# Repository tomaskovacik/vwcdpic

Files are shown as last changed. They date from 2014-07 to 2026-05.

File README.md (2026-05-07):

You can buy boards or finished emu at my store at tindie:



Full backup/mirror of original vwcdpic site is on <a href="https://web.archive.org/web/20110817024153/http://www.k9spud.com/vwcdpic/">archive.org</a>

<a href="https://github.com/tomaskovacik/vwcdpic/blob/master/vwcdpic-2.8pre3.asm">vwcdpic-2.8pre3.asm</a> - latest sourcecode on internet, with my <a href="https://github.com/tomaskovacik/vwcdpic/commits/master/vwcdpic-2.8pre3.asm">fixies</a>
	
<a href="https://raw.githubusercontent.com/tomaskovacik/vwcdpic/master/vwcdpic-3.x-2.7d-RCD300-1-pic12f629.hex">vwcdpic-3.x-2.7d-RCD300-1-pic12f629.hex</a> is only version works with RCD300 head unit(black one, no silver), if it works with other, for which 2.8 didn't, let me know please.

for ipod support look <a href="https://web.archive.org/web/20090427105500/http://www.k9spud.com/vwcdpic/devel/vwcdpic3/flash/">here</a>

<a href="https://web.archive.org/web/20090427105500/http://www.k9spud.com/vwcdpic/devel/vwcdpic-2.7d/ipod-vw-2.1.asm">iPod-VW Firmware v2.1 Source Code</a> - Use this for iPod 3G+ remote control support on most head units

<a href="https://web.archive.org/web/20090427105500/http://www.k9spud.com/vwcdpic/devel/vwcdpic3/flash/ipod-vw-2.2/ipod-vw-2.2.ConcertII_G5-3.x.asm">iPod-VW Firmware v2.2-Concert II Source Code</a> - Use this for iPod 4G/5G remote control support on Audi Concert II head units 

assemble plan for SMD version generated using <a href="https://github.com/openscopeproject/InteractiveHtmlBom">InteractiveHtmlBom</a> is <a href="https://tomaskovacik.github.io/vwcdpic/hw/bom/ibom.html">here</a>

assemble plan for THT version generated using <a href="https://github.com/openscopeproject/InteractiveHtmlBom">InteractiveHtmlBom</a> is <a href="https://tomaskovacik.github.io/vwcdpic/hw/bom_THT/ibom.html">here</a>

notes:
-------
2.8pre3
- better works with audi concert1/chorus1 head unit made by blaupunkt (previous,next CD works)
- switching from CDC to radio back to CDC works on concert1/chorus1
- tested with:
	- audi concert 1(blaupunkt)
	- audi concert 1(philips)
	- audi concert 2
	- chorus1(blaupunkt)
	- Symphony I
	- vw blaupunkt RadioNavigationSystem MCD
	- VW Passat Blaupunkt Gamma (similar to Gamma V)
	- Audi Symphony II BOSE
	- original project <a href="https://web.archive.org/web/20110811154456/http://www.k9spud.com/wiki/VWCDPIC:Compatible_Head_Units">list</a>
	
		- <a href="https://web.archive.org/web/20110811154456/http://www.k9spud.com/wiki/VWCDPIC:Compatible_Head_Units#Volkswagen">Volkswagen</a>
		
			- <a href="https://web.archive.org/web/20110811154456/http://www.k9spud.com/wiki/VWCDPIC:Compatible_Head_Units#New_Beetle">New Beetle</a>
			
			- <a href="https://web.archive.org/web/20110811154456/http://www.k9spud.com/wiki/VWCDPIC:Compatible_Head_Units#Touareg">Touareg</a>
			
			- <a href="https://web.archive.org/web/20110811154456/http://www.k9spud.com/wiki/VWCDPIC:Compatible_Head_Units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">Passat B3/B4 (1993+)</a>
			
			- <a href="https://web.archive.org/web/20110811154456/http://www.k9spud.com/wiki/VWCDPIC:Compatible_Head_Units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">EOS 3.2 (2008)</a>
			
			- <a href="https://web.archive.org/web/20110811154456/http://www.k9spud.com/wiki/VWCDPIC:Compatible_Head_Units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">Single DIN Monsoon</a>
			
			- <a href="https://web.archive.org/web/20110811154456/http://www.k9spud.com/wiki/VWCDPIC:Compatible_Head_Units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">Single DIN Monsoon with In-Dash CD Player</a>
			
			- <a href="https://web.archive.org/web/20110811154456/http://www.k9spud.com/wiki/VWCDPIC:Compatible_Head_Units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">Double DIN Monsoon</a>
			
			- <a href="https://web.archive.org/web/20110811154456/http://www.k9spud.com/wiki/VWCDPIC:Compatible_Head_Units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">Multi-Function Display (MFD)</a>
			
			- <a href="https://web.archive.org/web/20110811154456/http://www.k9spud.com/wiki/VWCDPIC:Compatible_Head_Units#Gamma_IV">Gamma IV</a>
			
			- <a href="https://web.archive.org/web/20110811154456/http://www.k9spud.com/wiki/VWCDPIC:Compatible_Head_Units#Gamma_V">Gamma V</a>
			
			- <a href="https://web.archive.org/web/20110811154456/http://www.k9spud.com/wiki/VWCDPIC:Compatible_Head_Units#RCD300">RCD300</a>
			
			- <a href="https://web.archive.org/web/20110811154456/http://www.k9spud.com/wiki/VWCDPIC:Compatible_Head_Units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">Blaupunkt R100</a>
			
			- <a href="https://web.archive.org/web/20110811154456/http://www.k9spud.com/wiki/VWCDPIC:Compatible_Head_Units#RNS300">RNS300</a>
			
			- <a href="https://web.archive.org/web/20110811154456/http://www.k9spud.com/wiki/VWCDPIC:Compatible_Head_Units#RN_S2_DVD">RN S2 DVD</a>

		- <a href="https://web.archive.org/web/20110811154456/http://www.k9spud.com/wiki/VWCDPIC:Compatible_Head_Units#Seat">Seat</a>
		
			- <a href="https://web.archive.org/web/20110811154456/http://www.k9spud.com/wiki/VWCDPIC:Compatible_Head_Units#Leon">Leon</a>
			
			- <a href="https://web.archive.org/web/20110811154456/http://www.k9spud.com/wiki/VWCDPIC:Compatible_Head_Units#Ibiza">Ibiza</a>

		- <a href="https://web.archive.org/web/20110811154456/http://www.k9spud.com/wiki/VWCDPIC:Compatible_Head_Units#Skoda">Skoda</a>
		
			- <a href="https://web.archive.org/web/20110811154456/http://www.k9spud.com/wiki/VWCDPIC:Compatible_Head_Units#Symphony">Symphony</a>

		- <a href="https://web.archive.org/web/20110811154456/http://www.k9spud.com/wiki/VWCDPIC:Compatible_Head_Units#Audi">Audi</a>
		
			- <a href="https://web.archive.org/web/20110811154456/http://www.k9spud.com/wiki/VWCDPIC:Compatible_Head_Units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">Audi Chorus II</a>

pinout:
--------------------
| signal | PIC pin  |
|---|---|
| +5v | 1 |
| GND | 8 |
| CLK: | 7 |
| DataIn: | 6 |
| DataOut: | 5 |
| serial 9600:  | 2 |

compile:
---------

http://www.micahcarrick.com/pic-programming-linux.html

for i in `ls *.asm|cut -d\. -f2`;do gpasm vwcdpic-2.$i.asm;done

about connectivity to music players
---------------------------------------------

all what is mentioned in archive on <a href="https://web.archive.org/web/20110817024153/http://www.k9spud.com/vwcdpic/">archive.org</a> should works.

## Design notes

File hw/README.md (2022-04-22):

HW part of vwcdpic project

- made in kicad http://kicad.org
- smd version
- tht version for home manufacture
- for better audio input level, build preamplifier: https://github.com/tomaskovacik/hw/tree/master/kicad/audio_preamplifier



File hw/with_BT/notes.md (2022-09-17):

1) - TEST OK
connect 12V to 12Vin
connect 12V to CDC_ENA_12V 
 check if 12V is present (switch Q2,Q1 works)

2)
connect jumper JP4

3) connect JP2 (R28, C34,C35 must be populated)

check if 3V6 is 3.6V, if not set using R19, R13)

program pic
connect to radio
check 3V6 voltage ripple while CDC is operational (??? or we can ignore this and listen to BT audio quality)

solder BT module, check if it connects, if so program it (disable STONES, set name etc...)

solder R4 -> enable communication PIC->BT

check audio ripple and mic bias (2V) whily BT in call

check overall audio quality

if noise from CDC is pressent, try JP1 or JP3

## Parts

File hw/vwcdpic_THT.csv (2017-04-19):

Id | Designator | Package | Quantity | Designation | Supplier and ref
1 | RADIO1 | Pin_Header_Straight_1x05 | 1 | CONN_01X05
2 | ICSP_UART1 | Pin_Header_Straight_1x04 | 1 | CONN_01X04
3 | C3,C2 | C_Rect_L7_W2.5_P5 | 2 | 100n
4 | U2 | TO92-STABIL | 1 | LM78L05ACZ
5 | U1 | DIP-8__300_ELL | 1 | PIC12F629
6 | R7,R6,R5 | Resistor_Horizontal_RM10mm | 3 | 3k3
7 | C1 | C_Radial_D5_L11_P2.5 | 1 | 1uF/6.3V
8 | R1 | Resistor_Horizontal_RM10mm | 1 | 10k

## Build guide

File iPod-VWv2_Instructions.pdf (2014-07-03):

iPod-VW Instructions

Connect the iPod to the control module and make sure the iPod is off before the head unit is turned on. Turning on the head unit should turn the iPod on. The iPod will turn on and off with the head unit as long as it is connected. If the iPod does not play within 2 seconds, pressing the “Scan” button (Play/Pause) one or more times should make the iPod play. The iPod may also be operated manually.

- Standard iPod functions

Play/Pause: “Scan” button
Previous Track: “Tune <”
Next Track: “Tune >”

There may be slight differences from radio to radio. Try all of the different buttons to discover which functions occur with each.

- Advanced iPod functions (aka “Mode 4”)

Advanced remote mode is best used when the iPod is placed in an inaccessible location, such as in the trunk or in the glove compartment. This mode most closely simulates an actual CD changer. Press the “Mix” button to place the iPod into advanced remote mode. While in this mode, all of the standard iPod functions still work. The display will now read “OK to Disconnect” and show a check mark. The iPod buttons are not usable in this mode. To return to normal mode, turn the iPod off with the head unit, then disconnect the remote connector. If the iPod will not return to normal mode, hold the “Menu” and center button down together until the iPod restarts.

The following functions are available in advanced mode:

Enter Shuffle Play Mode: “Mix”
(The iPod will pause after this command. Press “Scan” to resume play.)
Exit Shuffle Play Mode: “Tune <”
(The iPod will begin playing the track that is sequentially prior to the track you were playing.) Go to Main Playlist: “CD1”
Go to 1st Playlist: “CD2”
Go to 2nd Playlist: “CD3”
Go to 3rd Playlist: “CD4”
Go to 4th Playlist: “CD5”
Go to 5th Playlist: “CD6”
- PLAYLIST MANAGEMENT

The playlists are numbered in alphabetical order, starting with numbers. If you name your playlists “1”, “2”, “3”, “4”, and “5”, they are almost certain to be the first 5 playlists. Since iTunes displays the playlists in alphabetical order, the first 5 playlists shown under your iPod will be the 5 to play using the “CD2” – “CD6” buttons.

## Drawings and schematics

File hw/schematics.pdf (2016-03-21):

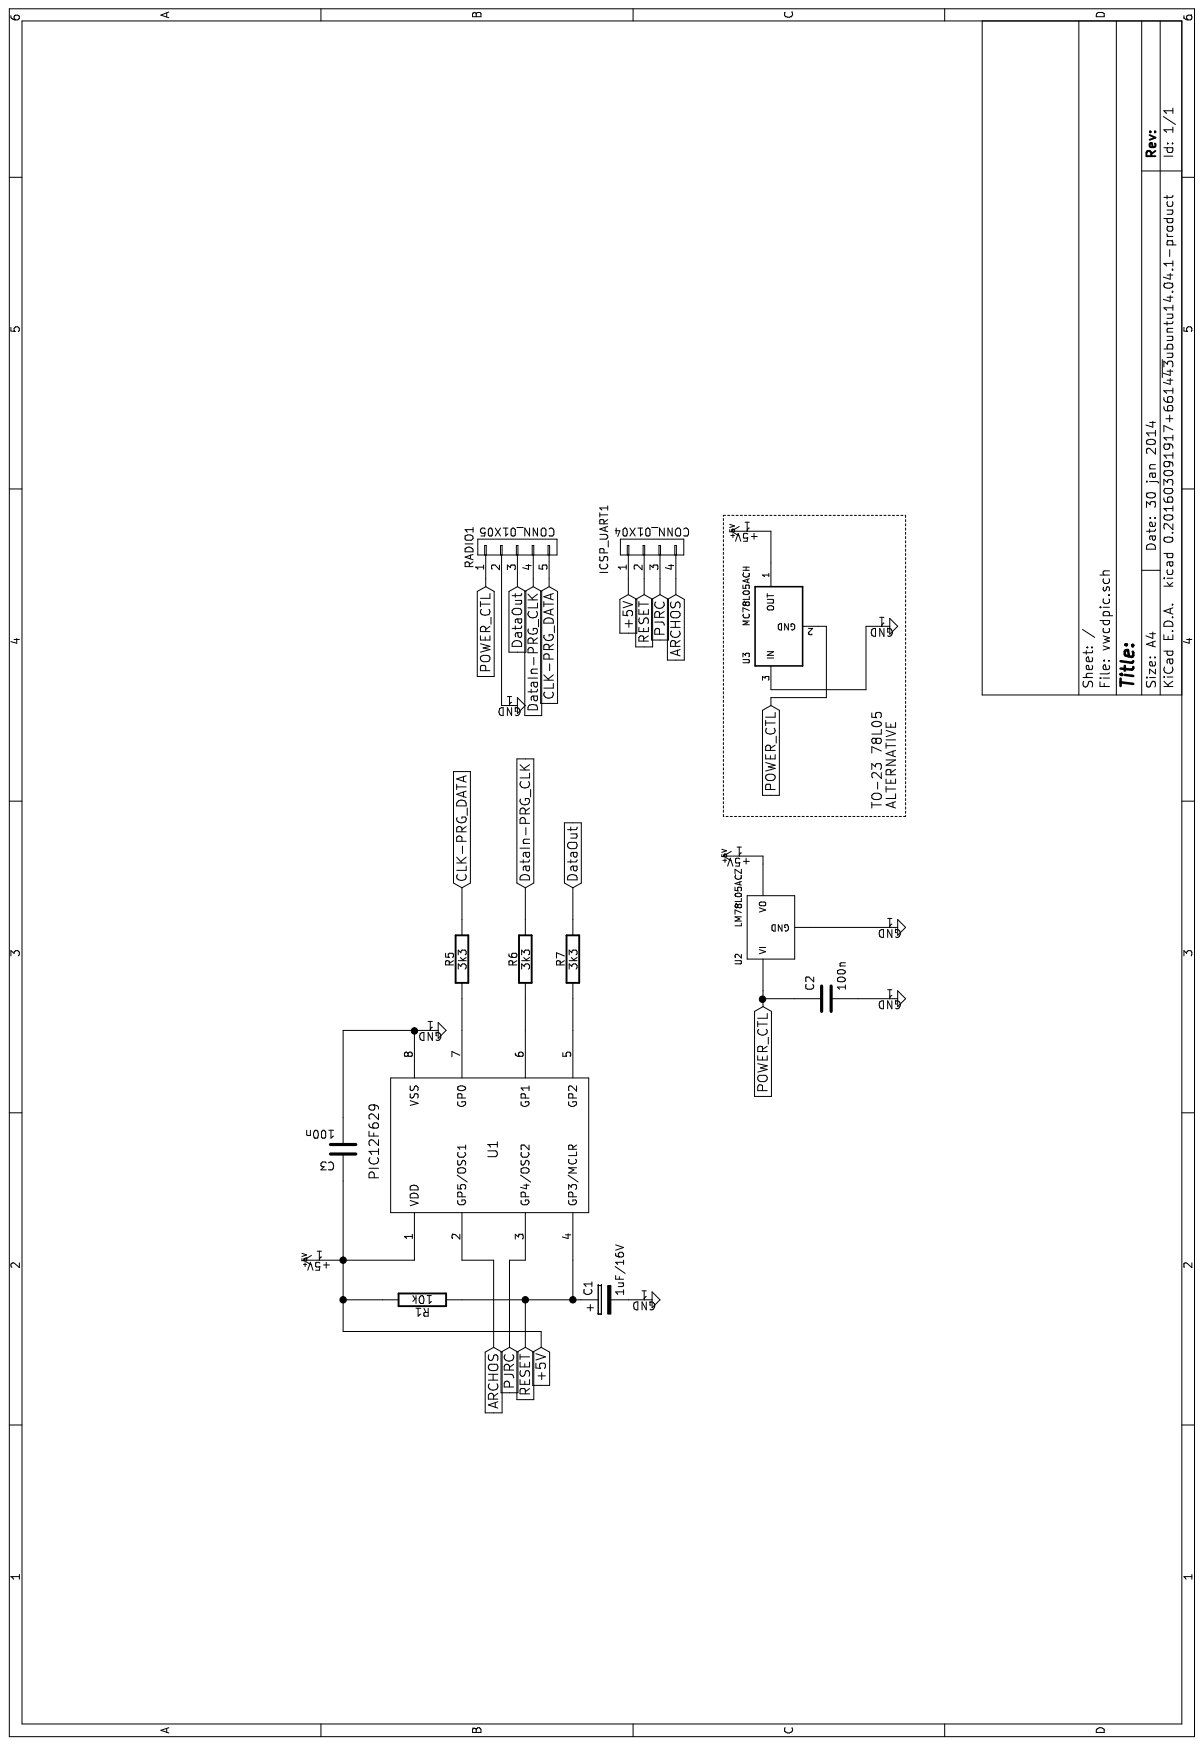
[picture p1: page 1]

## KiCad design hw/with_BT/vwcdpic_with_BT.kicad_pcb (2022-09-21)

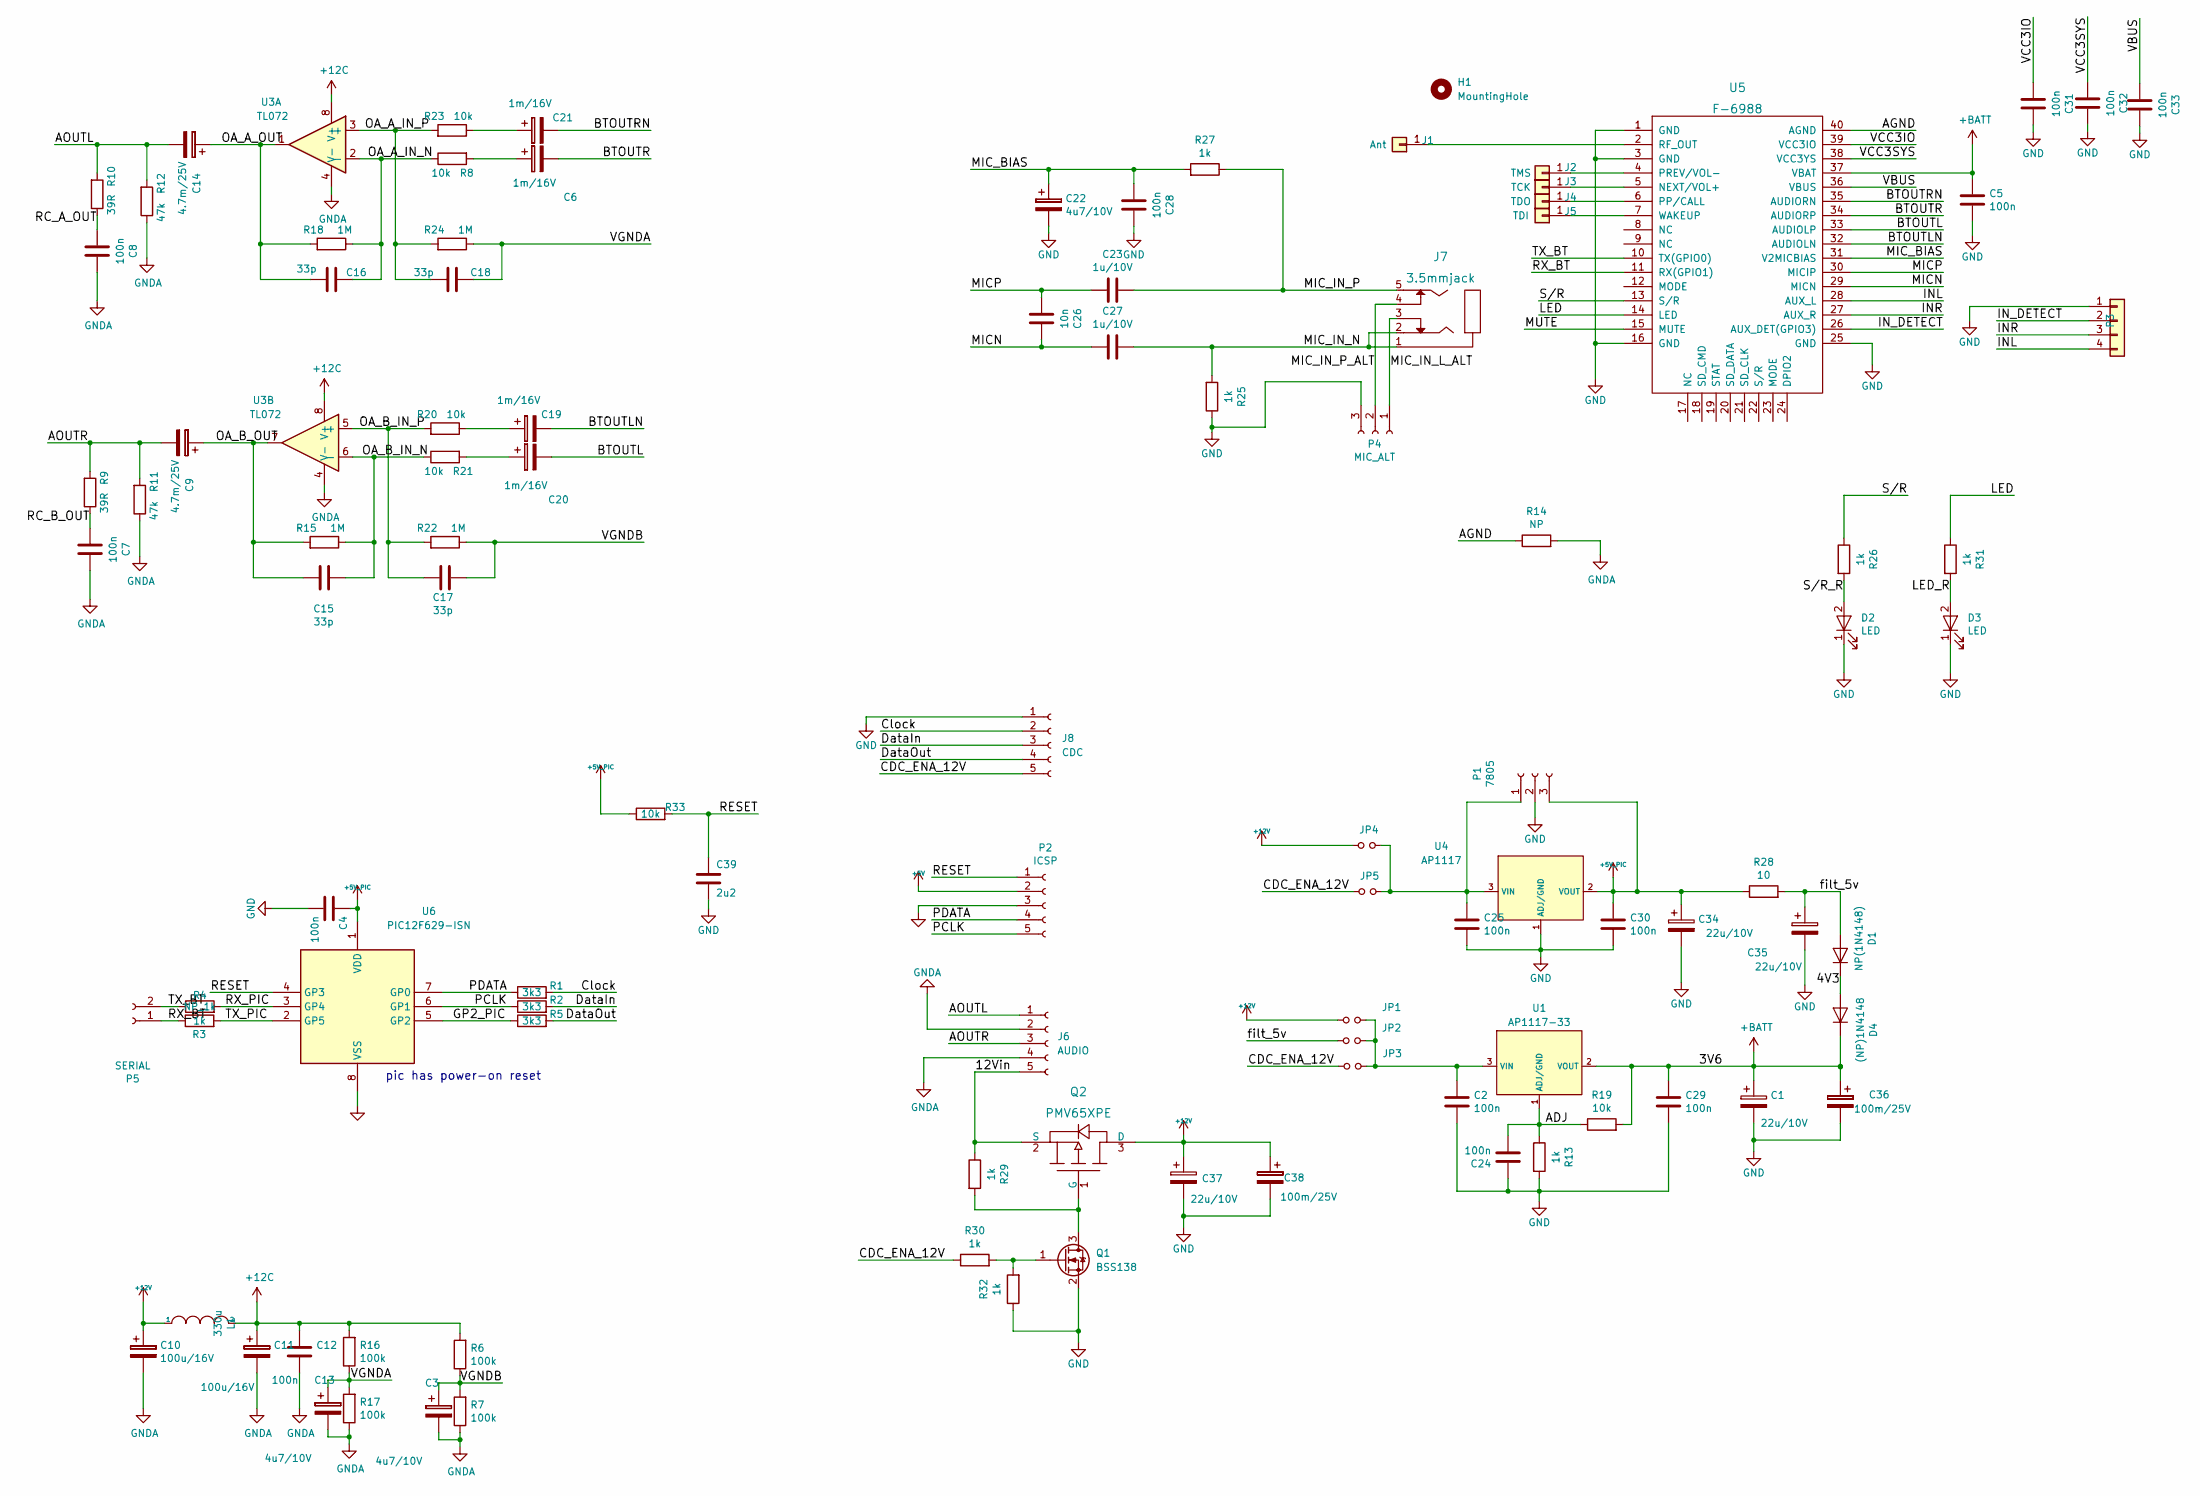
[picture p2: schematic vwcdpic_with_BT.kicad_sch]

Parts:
C1, C34, C35, C37: 22u/10V; TantalC_SizeB_EIA-3528_HandSoldering
C2, C4, C5, C7, C8, C12, C24, C25, C28, C29, C30, C31, C32, C33: 100n; C_0805_HandSoldering
C3, C13, C22: 4u7/10V; TantalC_SizeA_EIA-3216_Wave
C6, C19, C20, C21: 1m/16V; c_elec_5x5.8
C9, C14: 4.7m/25V; c_elec_5x5.8
C10, C11: 100u/16V; TantalC_SizeD_EIA-7343_HandSoldering
C15, C16, C17, C18: 33p; C_0805_HandSoldering
C23, C27: 1u/10V; C_1206_HandSoldering
C26: 10n; C_0805_HandSoldering
C36, C38: 100m/25V; c_elec_5x5.8
C39: 2u2; C_1206_HandSoldering
D1: NP(1N4148); MiniMELF_Handsoldering
D2, D3: LED; LED_0805_HandSoldering
D4: (NP)1N4148; MiniMELF_Handsoldering
H1: MountingHole; KM21
J1: Ant; 1pin_smd
J2: TMS; 1pin_smd
J3: TCK; 1pin_smd
J4: TDO; 1pin_smd
J5: TDI; 1pin_smd
J6: AUDIO; Pin_Header_Straight_1x05
J7: 3.5mmjack; 3.5mm_stereo_jack_PJ306M
J8: CDC; Pin_Header_Straight_1x05
JP1, JP2, JP3, JP4, JP5: Jumper_NO_Small; SolderJumper-2_P1.3mm_Open_TrianglePad1.0x1.5mm
L1: 330u; SMD-1210_Pol
P1: 7805; Pin_Header_Straight_1x03
P2: ICSP; Pin_Header_Straight_1x05
P3: AUX; Pin_Header_Straight_1x04
P4: MIC_ALT; Pin_Header_Straight_1x03
P5: SERIAL; Pin_Header_Straight_1x02
Q1: BSS138; SOT-23
Q2: PMV65XPE; SOT-23
R1, R2, R5: 3k3; R_0805_HandSoldering
R3, R13, R25, R26, R27, R29, R30, R31, R32: 1k; R_0805_HandSoldering
R4: NP_1k; R_0805_HandSoldering
R6, R7, R16, R17: 100k; R_0805_HandSoldering
R8, R19, R20, R21, R23, R33: 10k; R_0805_HandSoldering
R9, R10: 39R; R_0805_HandSoldering
R11, R12: 47k; R_0805_HandSoldering
R14: NP; R_0805_HandSoldering
R15, R18, R22, R24: 1M; R_0805_HandSoldering
R28: 10; R_0805_HandSoldering
U1: AP1117-33; AB2_SOT223
U3: TL072; SOIC-8-N
U4: AP1117; AB2_SOT223
U5: F-6988
U6: PIC12F629-ISN; SOIC-8-W_long_pads

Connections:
+12C: C11.1, C12.1, L1.2, R6.2, R16.2, U3.8 (V+)
+12V: C10.1, C37.1, C38.1, JP1.1, JP4.1, L1.1, Q2.3 (D)
+BATT: C1.1, C5.1, C29.1, C36.1, D4.1 (K), R19.2, U1.2 (VOUT), U5.37 (VBAT)
/4V3: D1.1 (K), D4.2 (A)
/12Vin: J6.5, Q2.2 (S), R29.1
/ADJ: C24.2, R13.1, R19.1, U1.1 (ADJ/GND)
/AGND: R14.1, U5.40 (AGND)
/AOUTL: C14.2, J6.1, R10.2, R12.2
/AOUTR: C9.2, J6.3, R9.2, R11.2
/BTOUTL: C20.2, U5.33 (AUDIOLP)
/BTOUTLN: C19.2, U5.32 (AUDIOLN)
/BTOUTR: C6.2, U5.34 (AUDIORP)
/BTOUTRN: C21.2, U5.35 (AUDIORN)
/CDC_ENA_12V: J8.5, JP3.1, JP5.1, R30.1
/Clock: J8.2, R1.2
/DataIn: J8.3, R2.2
/DataOut: J8.4, R5.2
/GP2_PIC: R5.1, U6.5 (GP2)
/INL: P3.4, U5.28 (AUX_L)
/INR: P3.3, U5.27 (AUX_R)
/IN_DETECT: P3.2, U5.26 (AUX_DET(GPIO3))
/LED: R31.1, U5.14 (LED)
/LED_R: D3.2 (A), R31.2
/MICN: C26.2, C27.1, U5.29 (MICN)
/MICP: C23.1, C26.1, U5.30 (MICIP)
/MIC_BIAS: C22.1, C28.1, R27.2, U5.31 (V2MICBIAS)
/MIC_IN_L_ALT: J7.3, P4.1
/MIC_IN_N: C27.2, J7.1, J7.2, R25.2
/MIC_IN_P: C23.2, J7.5, R27.1
/MIC_IN_P_ALT: J7.4, P4.2
/MUTE: U5.15 (MUTE)
/OA_A_IN_N: C16.2, R8.1, R18.1, U3.2 (-)
/OA_A_IN_P: C18.1, R23.2, R24.2, U3.3 (+)
/OA_A_OUT: C14.1, C16.1, R18.2, U3.1
/OA_B_IN_N: C15.2, R15.1, R21.1, U3.6 (-)
/OA_B_IN_P: C17.1, R20.2, R22.2, U3.5 (+)
/OA_B_OUT: C9.1, C15.1, R15.2, U3.7
/PCLK: P2.5, R2.1, U6.6 (GP1)
/PDATA: P2.4, R1.1, U6.7 (GP0)
/RC_A_OUT: C8.1, R10.1
/RC_B_OUT: C7.1, R9.1
/RESET: C39.1, P2.1, R33.2, U6.4 (GP3)
/RX_BT: P5.1, R3.1, U5.11 (RX(GPIO1))
/RX_PIC: R4.2, U6.3 (GP4)
/S/R: R26.1, U5.13 (S/R)
/S/R_R: D2.2 (A), R26.2
/TX_BT: P5.2, R4.1, U5.10 (TX(GPIO0))
/TX_PIC: R3.2, U6.2 (GP5)
/VBUS: C33.1, U5.36 (VBUS)
/VCC3IO: C31.1, U5.39 (VCC3IO)
/VCC3SYS: C32.1, U5.38 (VCC3YS)
/VGNDA: C13.1, C18.2, R16.1, R17.2, R24.1
/VGNDB: C3.1, C17.2, R6.1, R7.2, R22.1
/filt_5v: C35.1, D1.2 (A), JP2.1, R28.2
GND: C1.2, C2.2, C4.2, C5.2, C22.2, C24.1, C25.2, C28.2, C29.2, C30.2, C31.2, C32.2, C33.2, C34.2, C35.2, C36.2, C37.2, C38.2, C39.2, D2.1 (K), D3.1 (K), J8.1, P1.2, P2.3, P3.1, P4.3, Q1.2 (S), R13.2, R25.1, R32.1, U4.1 (ADJ/GND), U5.1 (GND), U5.3 (GND), U5.16 (GND), U5.25 (GND), U6.8 (VSS)
GNDA: C3.2, C7.2, C8.2, C10.2, C11.2, C12.2, C13.2, J6.2, J6.4, R7.1, R11.1, R12.1, R14.2, R17.1, U3.4 (V-)
unnamed: C2.1, JP1.2, JP2.2, JP3.2, U1.3 (VIN)
unnamed: C6.1, R8.2
unnamed: C19.1, R20.1
unnamed: C20.1, R21.2
unnamed: C21.1, R23.1
unnamed: C25.1, JP4.2, JP5.2, P1.1, U4.3 (VIN)
unnamed: J1.1, U5.2 (RF_OUT)
unnamed: J2.1, U5.4 (PREV/VOL-)
unnamed: J3.1, U5.5 (NEXT/VOL+)
unnamed: J4.1, U5.6 (PP/CALL)
unnamed: J5.1, U5.7 (WAKEUP)
unnamed: Q1.1 (G), R30.2, R32.2
unnamed: Q1.3 (D), Q2.1 (G), R29.2

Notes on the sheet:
pic has power-on reset

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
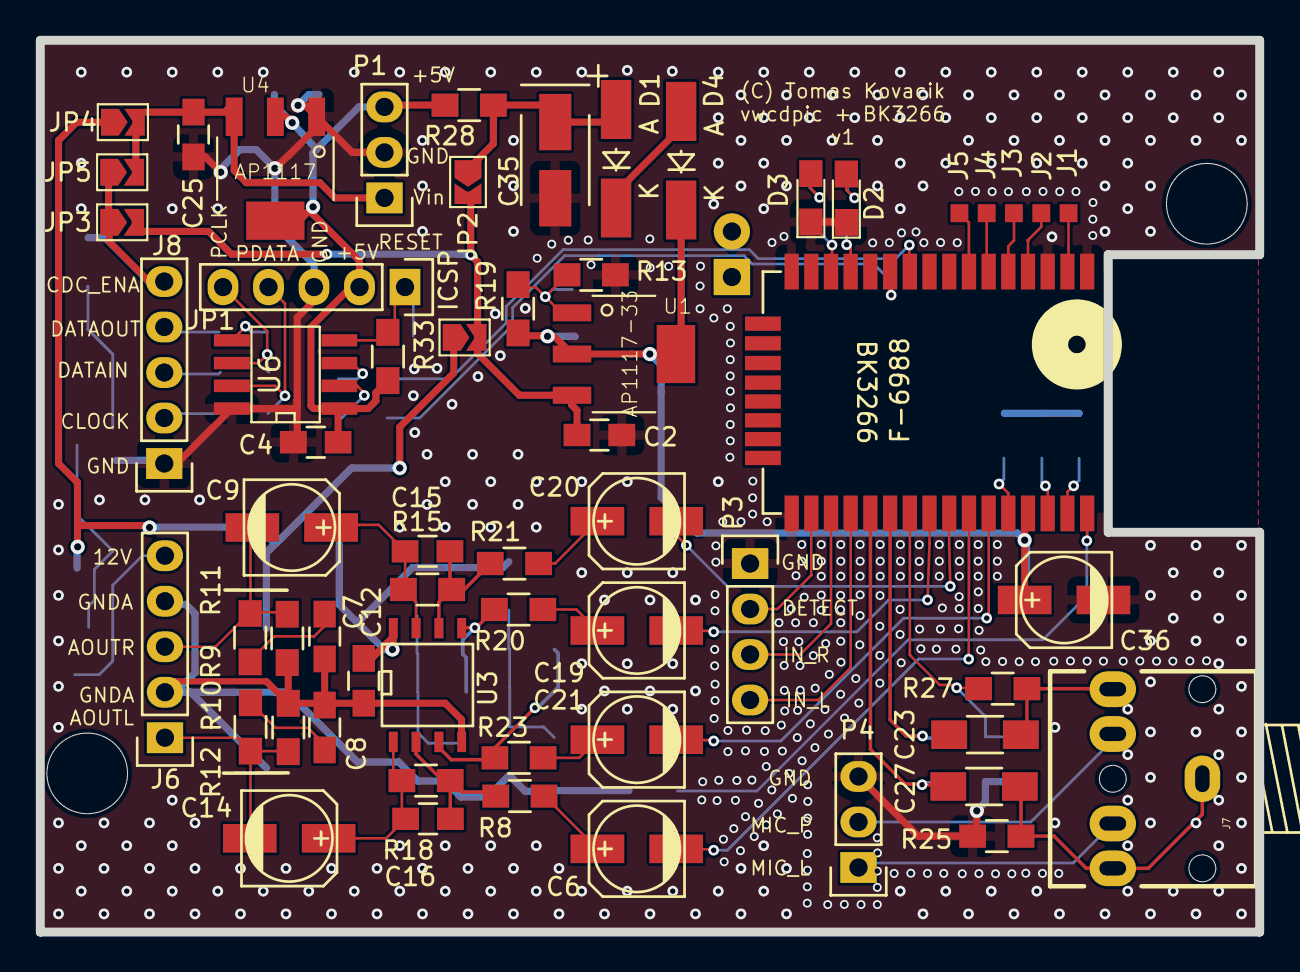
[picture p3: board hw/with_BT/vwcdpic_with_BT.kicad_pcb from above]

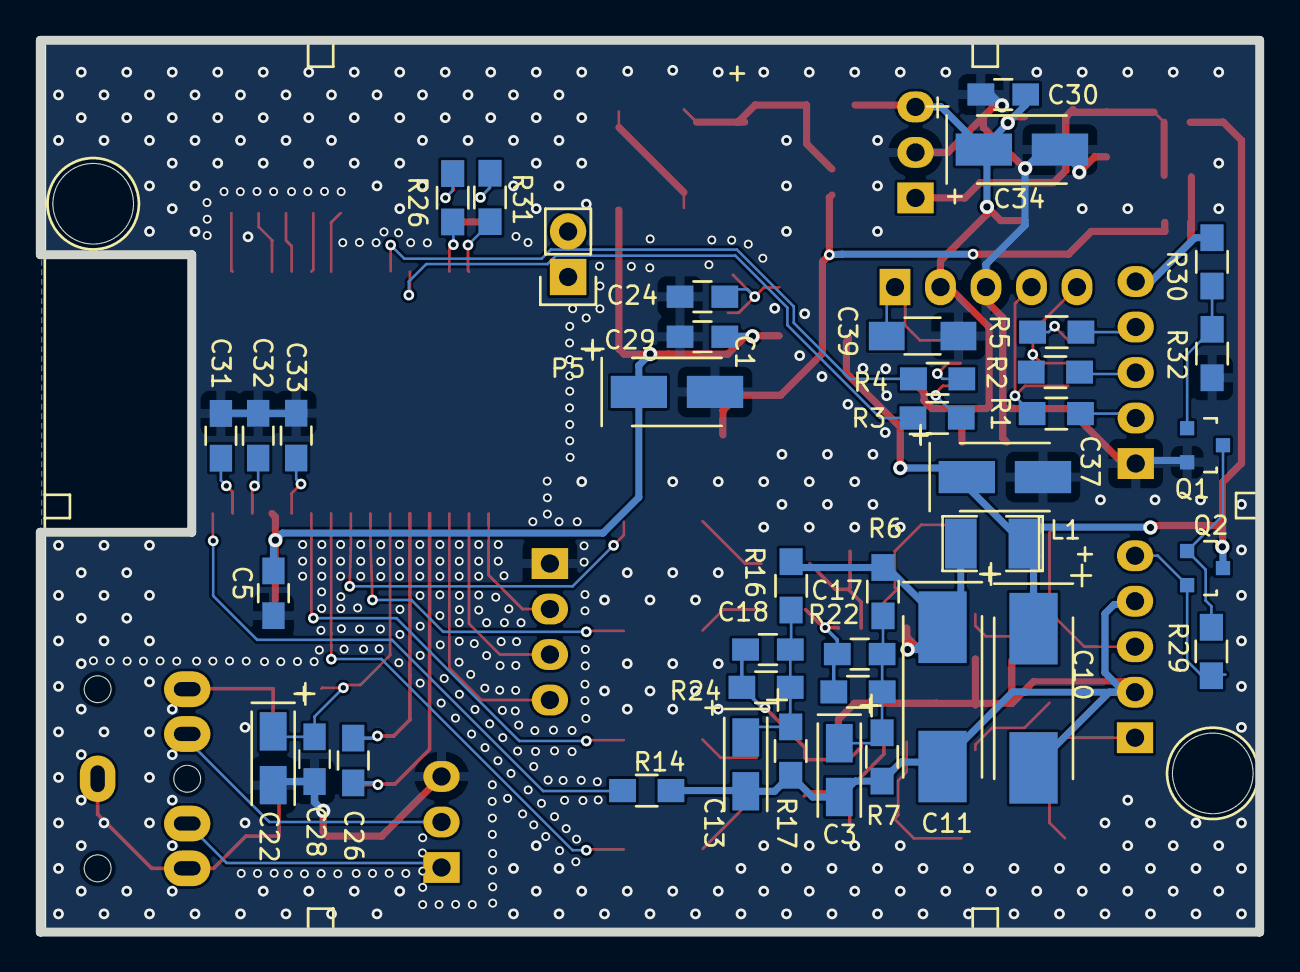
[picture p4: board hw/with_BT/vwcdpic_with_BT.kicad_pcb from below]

Board: 2 copper layers, 68.1 x 49.8 mm, 102 parts (42 on the bottom side), 69 nets.

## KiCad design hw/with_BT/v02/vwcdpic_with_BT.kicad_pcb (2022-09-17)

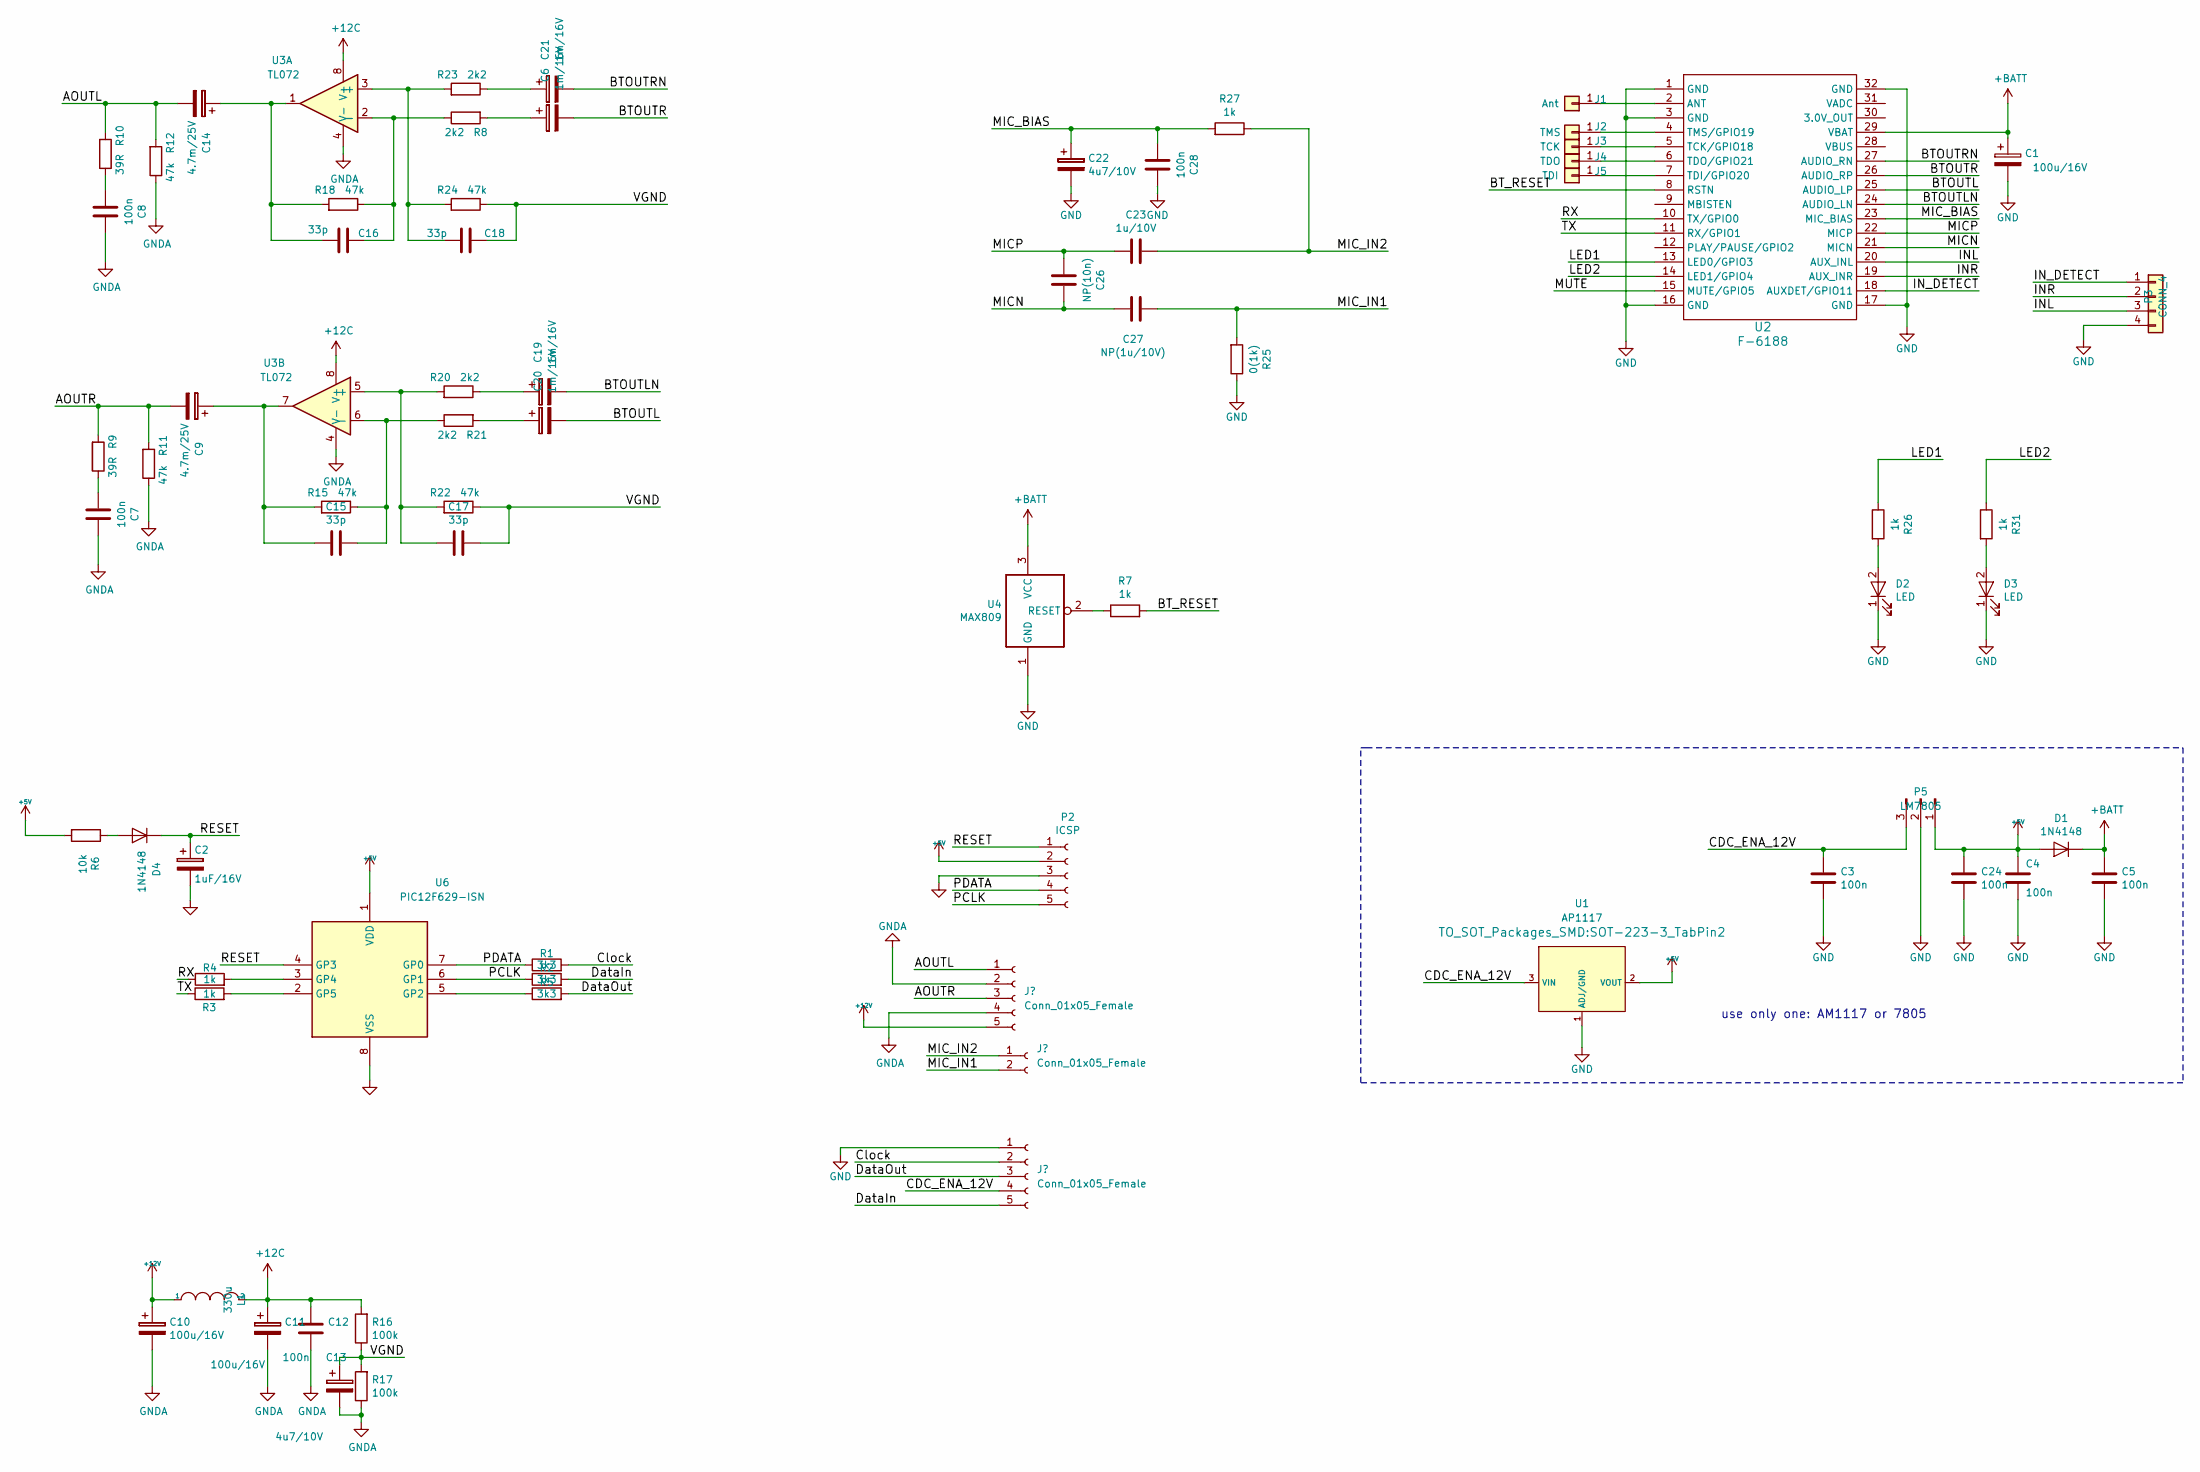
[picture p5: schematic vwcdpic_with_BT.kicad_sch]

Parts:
C1: 100u/16V; C_Rect_L7_W2.5_P5
C2: 1uF/16V; C_0805_HandSoldering
C3, C4, C5, C7, C8, C12, C24, C28: 100n; C_0805_HandSoldering
C6, C19, C20, C21: 1m/16V; CP_Elec_5x5.8
C9, C14: 4.7m/25V; c_elec_6.3x5.7
C10, C11: 100u/16V; CP_Tantalum_Case-D_EIA-7343-31_Hand
C13, C22: 4u7/10V; TantalC_SizeA_EIA-3216_Wave
C15, C16, C17, C18: 33p; C_0805_HandSoldering
C23: 1u/10V; C_1206_HandSoldering
C26: NP(10n); C_0805_HandSoldering
C27: NP(1u/10V); C_1206_HandSoldering
D1, D4: 1N4148; D_MiniMELF
D2, D3: LED; LED_0805_HandSoldering
J1: Ant; 1pin_smd
J2: TMS; 1pin_smd
J3: TCK; 1pin_smd
J4: TDO; 1pin_smd
J5: TDI; 1pin_smd
L1: 330u; SMD-1210_Pol
P2: ICSP; Pin_Header_Straight_1x05
P3: CONN_4; Pin_Header_Straight_1x04
P5: LM7805; Pin_Header_Straight_1x03
R1, R2, R5: 3k3; R_0805_HandSoldering
R3, R4, R7, R26, R27, R31: 1k; R_0805_HandSoldering
R6: 10k; R_0805_HandSoldering
R8, R20, R21, R23: 2k2; R_0805_HandSoldering
R9, R10: 39R; R_0805_HandSoldering
R11, R12, R15, R18, R22, R24: 47k; R_0805_HandSoldering
R16, R17: 100k; R_0805_HandSoldering
R25: 0(1k); R_0805_HandSoldering
U1: AP1117; SOT-223-3_TabPin2
U2: F-6188; F-6188_nosilk
U3: TL072; SOIC-8-N
U4: MAX809; SOT-23
U6: PIC12F629-ISN; SOIC-8-W_long_pads

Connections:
+5V: C4.1, C24.1, D1.2 (A), P2.2, P5.1, R6.2, U1.2 (VOUT), U6.1 (VDD)
+12C: C11.1, C12.1, L1.2, R16.2, U3.8 (V+)
+12V: C10.1, L1.1; also elsewhere on the board
+BATT: C1.1, C5.1, D1.1 (K), U2.29 (VBAT), U4.3 (VCC)
/AOUTL: C14.2, R10.2, R12.2; also elsewhere on the board
/AOUTR: C9.2, R9.2, R11.2; also elsewhere on the board
/BTOUTL: C20.2, U2.25 (AUDIO_LP)
/BTOUTLN: C19.2, U2.24 (AUDIO_LN)
/BTOUTR: C6.2, U2.26 (AUDIO_RP)
/BTOUTRN: C21.2, U2.27 (AUDIO_RN)
/BT_RESET: R7.2, U2.8 (RSTN)
/CDC_ENA_12V: C3.1, P5.3, U1.3 (VIN); also elsewhere on the board
/Clock: R1.2; also elsewhere on the board
/DataIn: R2.2; also elsewhere on the board
/DataOut: R5.2; also elsewhere on the board
/INL: P3.3, U2.20 (AUX_INL)
/INR: P3.2, U2.19 (AUX_INR)
/IN_DETECT: P3.1, U2.18 (AUXDET/GPIO11)
/LED1: R26.1, U2.13 (LED0/GPIO3)
/LED2: R31.1, U2.14 (LED1/GPIO4)
/MICN: C26.2, C27.1, U2.21 (MICN)
/MICP: C23.1, C26.1, U2.22 (MICP)
/MIC_BIAS: C22.1, C28.1, R27.2, U2.23 (MIC_BIAS)
/MIC_IN1: C27.2, R25.2; also elsewhere on the board
/MIC_IN2: C23.2, R27.1; also elsewhere on the board
/PCLK: P2.5, R2.1, U6.6 (GP1)
/PDATA: P2.4, R1.1, U6.7 (GP0)
/RESET: C2.1, D4.1 (K), P2.1, U6.4 (GP3)
/RX: R4.1, U2.10 (TX/GPIO0)
/TX: R3.1, U2.11 (RX/GPIO1)
/VGND: C13.1, C17.2, C18.2, R16.1, R17.2, R22.1, R24.1
GND: C1.2, C2.2, C3.2, C4.2, C5.2, C22.2, C24.2, C28.2, D2.1 (K), D3.1 (K), P2.3, P3.4, P5.2, R25.1, U1.1 (ADJ/GND), U2.1 (GND), U2.3 (GND), U2.16 (GND), U2.17 (GND), U2.32 (GND), U4.1 (GND), U6.8 (VSS); also elsewhere on the board
GNDA: C7.2, C8.2, C10.2, C11.2, C12.2, C13.2, R11.1, R12.1, R17.1, U3.4 (V-); also elsewhere on the board
unnamed: C6.1, R8.2
unnamed: C7.1, R9.1
unnamed: C8.1, R10.1
unnamed: C14.1, C16.1, R18.2, U3.1
unnamed: C9.1, C15.1, R15.2, U3.7
unnamed: C15.2, R15.1, R21.1, U3.6 (-)
unnamed: C16.2, R8.1, R18.1, U3.2 (-)
unnamed: C17.1, R20.2, R22.2, U3.5 (+)
unnamed: C18.1, R23.2, R24.2, U3.3 (+)
unnamed: C19.1, R20.1
unnamed: C20.1, R21.2
unnamed: C21.1, R23.1
unnamed: D2.2 (A), R26.2
unnamed: D3.2 (A), R31.2
unnamed: D4.2 (A), R6.1
unnamed: J1.1, U2.2 (ANT)
unnamed: J2.1, U2.4 (TMS/GPIO19)
unnamed: J3.1, U2.5 (TCK/GPIO18)
unnamed: J4.1, U2.6 (TDO/GPIO21)
unnamed: J5.1, U2.7 (TDI/GPIO20)
unnamed: R3.2, U6.2 (GP5)
unnamed: R4.2, U6.3 (GP4)
unnamed: R5.1, U6.5 (GP2)
unnamed: R7.1, U4.2 (RESET)

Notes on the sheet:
use only one: AM1117 or 7805

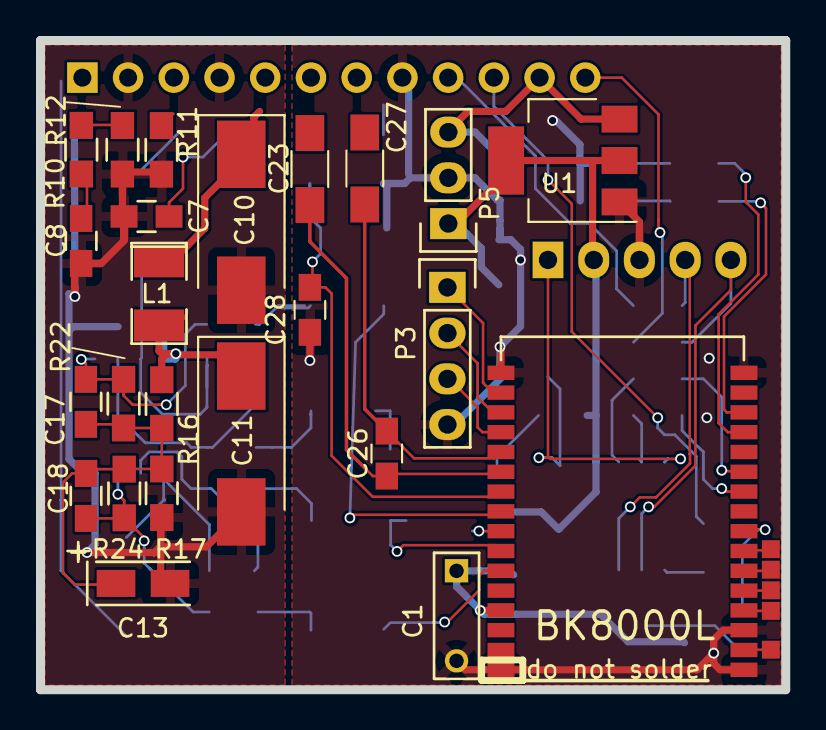
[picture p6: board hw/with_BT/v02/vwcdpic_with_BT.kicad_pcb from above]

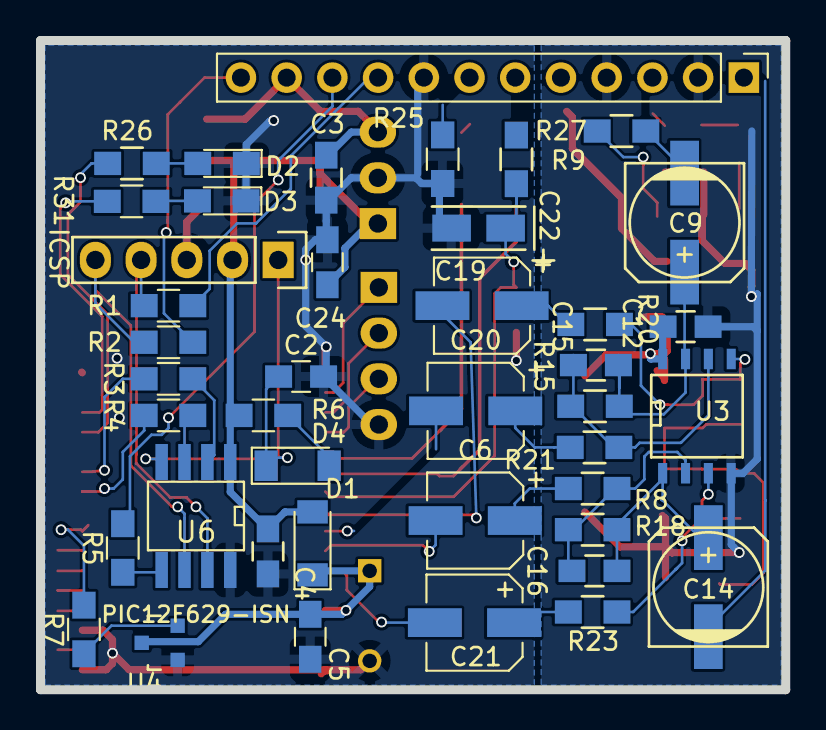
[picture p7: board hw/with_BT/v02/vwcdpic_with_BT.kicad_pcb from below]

Board: 2 copper layers, 41.4 x 36.1 mm, 71 parts (42 on the bottom side), 57 nets.

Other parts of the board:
P1: CONN_10; Pin_Header_Straight_1x12_Pitch2.54mm

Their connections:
+12V: P1.5; also elsewhere on the board
/AOUTL: P1.1; also elsewhere on the board
/AOUTR: P1.3; also elsewhere on the board
/CDC_ENA_12V: P1.11; also elsewhere on the board
/Clock: P1.9; also elsewhere on the board
/DataIn: P1.12; also elsewhere on the board
/DataOut: P1.10; also elsewhere on the board
/MIC_IN1: P1.7; also elsewhere on the board
/MIC_IN2: P1.6; also elsewhere on the board
GND: P1.8; also elsewhere on the board
GNDA: P1.2, P1.4; also elsewhere on the board

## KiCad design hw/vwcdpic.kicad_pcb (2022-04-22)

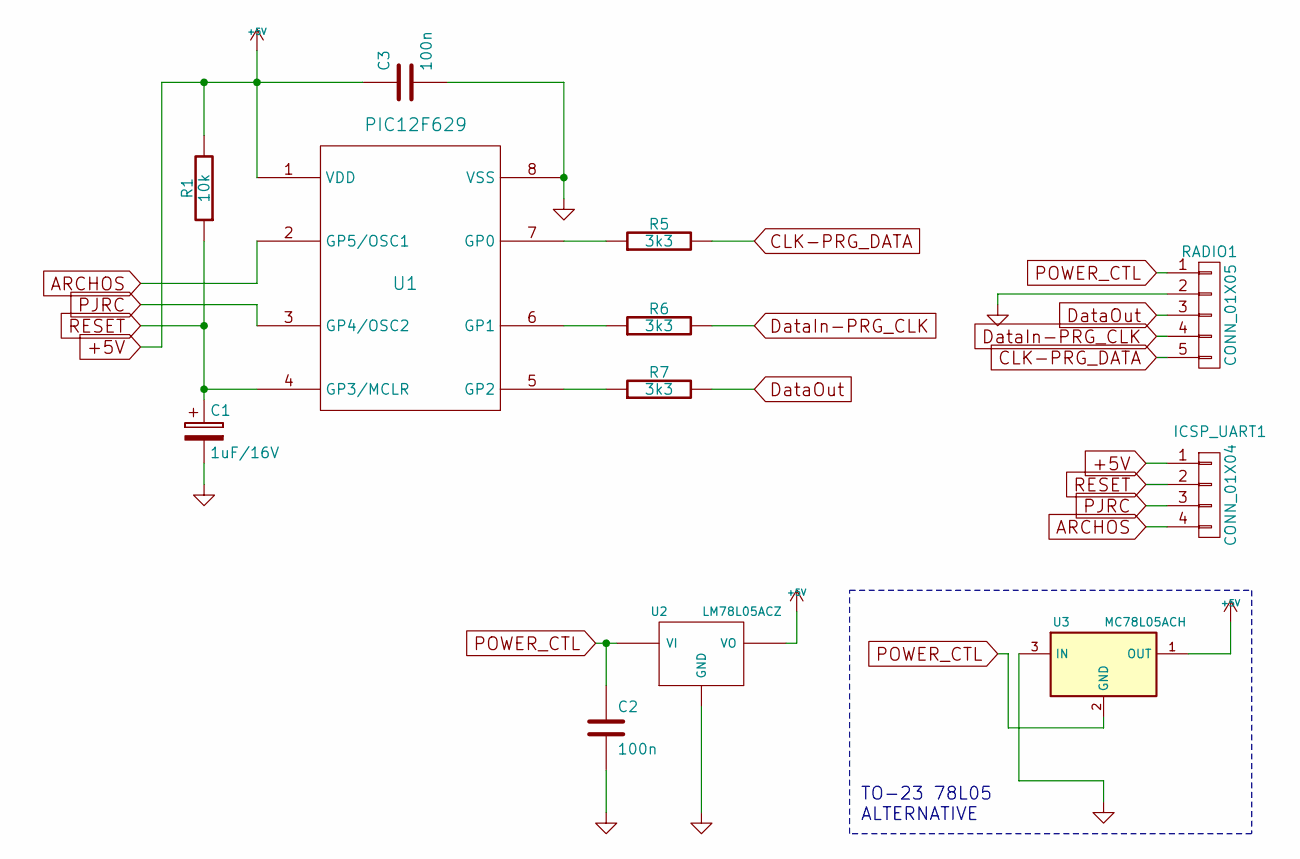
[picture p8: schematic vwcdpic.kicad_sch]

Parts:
C1: 1uF/16V; C_0805_HandSoldering
C2, C3: 100n; C_0805
ICSP_UART1: CONN_01X04; Pin_Header_Straight_1x04
R1: 10k; R_0805
R5, R6, R7: 3k3; R_0805
RADIO1: CONN_01X05; Pin_Header_Straight_1x05
U1: PIC12F629; SOIC-8-W_long_pads
U2: LM78L05ACZ; SOT-223-REGULATOR
U3: MC78L05ACH; SOT-23_Handsoldering

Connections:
+5V: C3.1, ICSP_UART1.1, R1.2, U1.1 (VDD), U2.VO, U3.1 (OUT)
ARCHOS: ICSP_UART1.4, U1.2 (GP5/OSC1)
CLK-PRG_DATA: R5.2, RADIO1.5; also elsewhere on the board
DataIn-PRG_CLK: R6.2, RADIO1.4; also elsewhere on the board
DataOut: R7.2, RADIO1.3; also elsewhere on the board
GND: C1.2, C2.2, C3.2, RADIO1.2, U1.8 (VSS), U2.GND, U3.3 (IN); also elsewhere on the board
unnamed: R5.1, U1.7 (GP0)
unnamed: R6.1, U1.6 (GP1)
unnamed: R7.1, U1.5 (GP2)
PJRC: ICSP_UART1.3, U1.3 (GP4/OSC2)
POWER_CTL: C2.1, RADIO1.1, U2.VI, U3.2 (GND); also elsewhere on the board
RESET: C1.1, ICSP_UART1.2, R1.1, U1.4 (GP3/MCLR)

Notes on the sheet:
TO-23 78L05 ALTERNATIVE

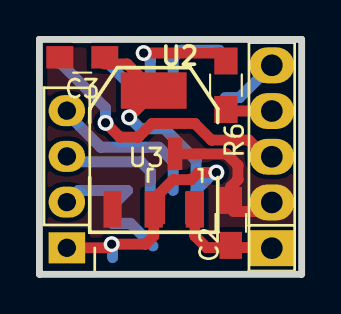
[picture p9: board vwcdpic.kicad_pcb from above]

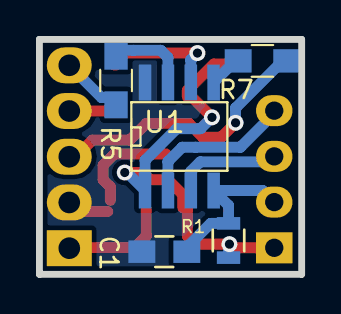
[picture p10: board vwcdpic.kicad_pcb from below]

Board: 2 copper layers, 14.6 x 13.1 mm, 12 parts (5 on the bottom side), 12 nets.

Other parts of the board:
RADIO: CONN_01X05; Pin_Header_Straight_1x05

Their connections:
CLK-PRG_DATA: RADIO.5; also elsewhere on the board
DataIn-PRG_CLK: RADIO.4; also elsewhere on the board
DataOut: RADIO.3; also elsewhere on the board
GND: RADIO.2; also elsewhere on the board
POWER_CTL: RADIO.1; also elsewhere on the board

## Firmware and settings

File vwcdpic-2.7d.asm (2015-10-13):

; -*- tab-width: 4 -*-
; VW CD Changer Protocol Implementation 
; For use on PIC12F6XX at 4MHz/5VDC
;
; Copyright (c) 2002-2005, K9spud LLC.
;
; This program is free software; you can redistribute it and/or
; modify it under the terms of the GNU General Public License
; as published by the Free Software Foundation; either version 2
; of the License, or (at your option) any later version.
;
; This program is distributed in the hope that it will be useful,
; but WITHOUT ANY WARRANTY; without even the implied warranty of
; MERCHANTABILITY or FITNESS FOR A PARTICULAR PURPOSE.  See the
; GNU General Public License for more details.
;
; You should have received a copy of the GNU General Public License
; along with this program; if not, write to the Free Software
; Foundation, Inc., 59 Temple Place - Suite 330, Boston, MA  02111-1307, USA.

;; Please visit http://www.k9spud.com/ where you can find the latest 
;; version of this software and information on building the hardware 
;; needed to run this software.
;;
;; If you sell devices derived from this software, make sure you read
;; and strictly adhere to the provisions set forth in the GNU General Public 
;; License. Specifically, any modifications you make to this source code
;; must be made available to the public under the GNU GPL.
;;
;; Credits
;; -------
;; Andy Wilson <awilson@NOSPAM.microsoft.com> - Monsoon protocol info
;; Paul Stewart <stewart@NOSPAM.parc.com> - Monsoon debugged code
;; Svetoslav Vassilev <svetoslav.vassilev@NOSPAM.excite.com> - Double DIN fixes
;; Tony Gilbert <tony.gilbert@NOSPAM.orange.co.uk> - Blaupunkt Gamma V codes
;; Adam Yellen <adam@NOSPAM.yellen.com> - Mk3 command codes
;; Paul Burgess <pburgess@NOSPAM.babson.edu> - Audi Concert command codes
;; Hans-Dieter Wohlmuth <hans-dieter.wohlmuth@NOSPAM.infineon.com> -
;;		Suggested changes to improve Audi Concert II remote control capability.
;;
;; $Log: vwcdpic.asm,v $
;; Revision 1.62.4.8  2005/05/14 19:14:43  edwards
;; Tagged for v2.7d release.
;;
;; Revision 1.62.4.7  2005/05/10 04:45:39  edwards
;; Acknowledge bit wasn't being set correctly.
;; CD Loaded packets weren't being generated correctly.
;; Added RCD300 hold down mix button command.
;;
;; Revision 1.62.4.6  2005/05/01 21:40:45  edwards
;; Fixed a little bug with MIX light being inverted.
;;
;; Revision 1.62.4.5  2005/05/01 08:00:18  edwards
;; First attempt at inverting all head unit packet data bits so that it is easier to
;; read the source code.
;;
;; Revision 1.62.4.4  2005/05/01 04:41:37  edwards
;; Backed out previous serial fix and applied a different fix that is more correct.
;; Added support for VWCDPIC v3.x hardware layout.
;; Added support for more PICmicro chips that are compatible.
;; Started migrating Volkswagen CMR to mainline branch.
;;
;; Revision 1.62.4.3  2005/04/30 07:35:58  edwards
;; Modified timing of 19.2Kbps serial routine. Now works on PIC12F683.
;;
;; Revision 1.62.4.2  2005/04/24 06:41:36  edwards
;; Started adding support for new PIC12F683 chip. Untested right now.
;;
;; Revision 1.62.4.1  2005/04/24 05:01:24  edwards
;; Modified head unit refresh period from 100ms between refresh packets
;; down to 50ms between refresh packets. Maybe this will help with RCD300
;; head units.
;;
;; Revision 1.62  2004/07/16 01:02:03  edwards
;; Added track rollover for Audi Concert II jog wheel.
;;
;; Revision 1.61  2004/07/15 12:21:56  edwards
;; Set version strings for v2.7b.
;;
;; Revision 1.60  2004/07/15 12:12:07  edwards
;; Added SendDisplayBytesInitCD routine for loading initial CD information.
;;
;; Revision 1.59  2004/07/15 11:28:49  edwards
;; Some Archos Jukeboxes appearantly don't have their own pull-up resistor 
;; for serial remote control.
;;
;; Revision 1.58  2004/07/04 07:25:17  edwards
;; Set version strings for v2.7 release.
;;
;; Revision 1.57  2004/07/04 03:12:07  edwards
;; Remapped commands for Archos remote control.
;;
;; Revision 1.56  2004/06/30 07:36:22  edwards
;; Fixed some bugs setting up the Archos 9600 baud serial TX pin.
;;
;; Revision 1.55  2004/06/29 06:33:36  edwards
;; Added TrackLeadIn state, fixed bugs in ACK support.
;;
;; Revision 1.54  2004/06/28 06:34:25  edwards
;; Fixed some bugs and re-enabled Archos support
;;
;; Revision 1.51  2004/06/28 03:23:49  edwards
;; Implemented new state machine w/command ACK support.
;;
;; Revision 1.47  2004/06/27 08:51:43  edwards
;; First pass at new command recognition code.
;;
;; Revision 1.45  2004/06/25 03:56:33  edwards
;; documenting more protocol info
;;
;; Revision 1.46  2004/06/27 08:49:31  edwards
;; TX buffer and command RX buffer were allocated overlapping memory regions.
;;
;; Revision 1.44  2004/05/16 22:18:58  edwards
;; Fixed some bugs in disabling Archos support. Caused MIX6
;; and DN/UP for Mk3 head units to lock up the VWCDPIC firmware in an
;; endless loop.
;;
;; Revision 1.43  2004/05/02 19:20:14  edwards
;; Disabled Archos Jukebox support to see if that helps European head unit
;; problems.
;;
;; Revision 1.42  2004/01/21 04:31:16  edwards
;; Added support for compiling against PIC16F627 target.
;;
;; Revision 1.41  2004/01/19 00:17:45  edwards
;; Final cleanup for v2.6 release.
;;
;; Revision 1.40  2004/01/18 23:27:54  edwards
;; no message
;;
;; Revision 1.39  2004/01/18 20:22:23  edwards
;; Added back Archos support (still untested).
;;
;; Revision 1.38  2004/01/18 06:36:24  edwards
;; Fixed code that spits out invalid command packet bytes captured.
;;
;; Revision 1.37  2004/01/18 05:19:37  edwards
;; Finally got the string queuing code working bug free.
;;
;; Revision 1.36  2004/01/18 03:18:21  edwards
;; Fixed some bugs in the new code.
;;
;; Revision 1.35  2004/01/18 02:00:58  edwards
;; added implementation for EnqueueString
;;
;; Revision 1.34  2004/01/18 00:10:14  edwards
;; no comment
;;
;; Revision 1.33  2004/01/17 19:18:50  edwards
;; Adding support for an outbound serial string print queue.
;;
;; Revision 1.32  2004/01/13 06:41:32  edwards
;; Adding back support for recognizing commands.
;;
;; Revision 1.31  2004/01/13 05:09:04  edwards
;; no message
;;
;; Revision 1.30  2004/01/13 04:48:01  edwards
;; interim improvements to capture code.
;;
;; Revision 1.29  2004/01/12 06:58:26  edwards
;; Starting to work on reverse bit order command capture. This bit ordering
;; will make it more natural to read command bits as they were captured.
;;
;; Revision 1.28  2004/01/12 04:48:59  edwards
;; Filter seems to work, but doesn't solve the problem.
;;
;; Revision 1.27  2004/01/12 01:30:27  edwards
;; second try at improved command noise filtering
;;
;; Revision 1.26  2004/01/12 01:08:09  edwards
;; first try at improved command noise filtering
;;
;; Revision 1.25  2003/10/09 07:29:28  edwards
;; Increased delay between bytes sent to the head unit to 700us per suggestion
;; from Svet. Maybe helps with late 2003 Wolfsburg double din drop out problem.
;;
;; Revision 1.24  2003/09/28 18:55:00  edwards
;; Committed Svet's changes to cvs repository.
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

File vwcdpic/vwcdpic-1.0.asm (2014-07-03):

;; Volkswagen CD Changer Emulator
;; For use on PIC16F627 at 4MHz/5VDC
;;
;; Copyright (c) 2002, Edward Schlunder <zilym@yahoo.com>

; Note:	4MHz / 4 = 1MHz. 1/1MHz = 1us.
;       So each PIC instruction takes one microsecond long.
	
	LIST P=16F627, R=DEC

#include <p16f627.inc>

;--------------------------------------------------------------------------
; Connections
;--------------------------------------------------------------------------
; PIC RA3 -> VW Pin 2 Clock  to Head Unit
; PIC RA2 -> VW Pin 1 Data   to Head Unit
; PIC RB0 <- VW Pin 4 Data from Head Unit
; Make sure PIC and VW Head Unit have common GND.
; 
; PIC RB6 -> PJRC RX
; PIC RB7 <- PJRC TX
; Make sure PIC and PJRC MP3 Player have common GND.
;--------------------------------------------------------------------------
SCLK		EQU	3
SRX		EQU	2
PWTX		EQU	0

SerialTX	EQU	6
SerialRX	EQU	7

HIGHTHRESHOLD	EQU	39		; timer counts greater than this
					; are HIGH bits. Otherwise LOW bit.

REFRESH_PERIOD	EQU	15		; refresh head unit every 15ms
;--------------------------------------------------------------------------
; Variables
;--------------------------------------------------------------------------
ScratchPadRam   EQU     0x20
sendreg		EQU	ScratchPadRam+0
sendhexreg	EQU	ScratchPadRam+1
disc		EQU	ScratchPadRam+2
discload	EQU	ScratchPadRam+3	; next disc number to enable head
DISCMIN		EQU	0x19
DISCMAX		EQU	0x1F
track		EQU	ScratchPadRam+4

scanptr		EQU	ScratchPadRam+5
scanbyte	EQU	ScratchPadRam+6
buttonbyte1	EQU	ScratchPadRam+7
buttonbyte2	EQU	ScratchPadRam+8

intwsave	EQU	ScratchPadRam+10
intstatussave	EQU	ScratchPadRam+11
intfsrsave	EQU	ScratchPadRam+12

serialbit	EQU	ScratchPadRam+13
serialbyte	EQU	ScratchPadRam+14

capdone		EQU	0
mix		EQU	1
serialflag	EQU	2
progflags	EQU	ScratchPadRam+15
captime		EQU	ScratchPadRam+16 ; timer count of low pulse (temp)
capbit		EQU	ScratchPadRam+17 ; bits left to capture for this byte
capptr		EQU	ScratchPadRam+18 ; pointer to packet capture buffer loc
capbuffer	EQU	0xA0
capbufferend	EQU	0xF0

;--------------------------------------------------------------------------
; Program Code
;--------------------------------------------------------------------------
	ORG	0
	goto	Start

;--------------------------------------------------------------------------
; Interrupt Service Routine
; 
; Interrupt Sources:
;	RB0/INT Used for recieving head unit button commands
;	TMR0	Used for timing head unit button command pulse width
;	TMR
;	RB[4..7] on Change
;		Used for recieving 19.2Kbps serial data from PC/PJRC
;--------------------------------------------------------------------------
	ORG	4
	movwf	intwsave	; preserve w register
	swapf	STATUS, w	; preserve status register
	movwf	intstatussave

	movf	TMR0, w		; save a copy of current TMR0 count
	movwf	captime		; in case PWTXCaptureBit needs it

	movf	FSR, w		; preserve FSR register
	movwf	intfsrsave
	
PWTXCaptureISR
	btfss	INTCON, INTF	; RB0/INT interrupt (PWTX Capture)?
	goto	SerialISR

	clrf	TMR0		; restart timer
	bcf	INTCON, INTF	; clear interrupt flag

	btfsc	PORTB, PWTX
	goto	PWTXCaptureBit

PWTXStartTimer
	;; We have interrupted at beginning of low pulse (falling edge)
	;; Low pulse length must be timed to determine bit value

	bcf	INTCON, T0IF	; clear TMR0 overflow flag
	bsf	INTCON, T0IE	; enable TMR0 interrupt on overflow
	
	bsf	STATUS, RP0	; select data bank 1
	ERRORLEVEL -302
	bsf	OPTION_REG, INTEDG ; set interrupt on rising edge
	ERRORLEVEL +302
	bcf	STATUS, RP0	; go back to data bank 0

	goto	EndInterrupt

PWTXCaptureBit
	;; We have interrupted at beginning of high pulse (rising edge)
	;; High pulse length doesn't matter. We need to check out
	;; captured low pulse width if we are capturing data at the moment

	bsf	STATUS, RP0	; select data bank 1
	ERRORLEVEL -302
	bcf	OPTION_REG, INTEDG ; set interrupt on falling edge
	ERRORLEVEL +302
	bcf	STATUS, RP0	; go back to data bank 0

	btfss	INTCON, T0IE	; are we trying to capture data?
	goto	EndInterrupt

	bcf	INTCON, T0IE	; turn off capturing time for high pulse

	movf	capptr, w	; load capture pointer into indirect pointer
	movwf	FSR

	movlw	HIGHTHRESHOLD	; is the timer count larger than the
	subwf	captime, w	; HIGH bit threshold value?
	rrf	INDF, f		; save captured bit into capture buffer

	incfsz	capbit, f	; have we collected all 8 bits?
	goto	EndInterrupt

	incf	FSR, f		; increment capture pointer
	movlw	-8		; start capturing another 8 bits
	movwf	capbit
	
	movlw	capbufferend	; have we overflowed the 
	subwf	FSR, w		; capture buffer?
	btfss	STATUS, Z
	goto	ClearCapByte

	movlw	capbuffer	; yes, roll over to beginning
	movwf	FSR

ClearCapByte
	clrf	INDF		; starting new capture byte, initialize
				; byte to zeros for uneven captured bytes
	movf	FSR, w		; save capture pointer
	movwf	capptr

	goto	EndInterrupt

SerialISR
	btfss	INTCON, RBIF	; did a RB interrupt on change occur?
	goto	TMR0ISR

	bcf	INTCON, RBIF	; clear interrupt flag
	bsf	progflags, serialflag
	
	btfss	PORTB, SerialRX	; is this a start bit?
	goto	TMR0ISR	

	clrf	serialbyte
	movlw	-8		; capture 8 bits

	; [(3 or 4) + 18] microseconds to get here
	; 19200 bits per second. 5.2083333e-5 seconds per bit = 52us per bit.
	call	Wait56

SerialCaptureLoop
	bcf	STATUS, C	
	btfss	PORTB, SerialRX
	bsf	STATUS, C	

	rrf	serialbyte, f	; save current bit into capture byte
	call	Wait44
	addlw	1
	btfss	STATUS, Z
	goto	SerialCaptureLoop

	nop
	;btfsc	PORTB, SerialRX	; are we getting a valid stop bit?
	bsf	progflags, serialflag

TMR0ISR
	btfss	INTCON, T0IE	; is timer 0 overflow interrupt enabled?
	goto	EndInterrupt
	btfss	INTCON, T0IF	; if so, did a timer 0 overflow occur?
	goto	EndInterrupt

	bcf	INTCON, T0IE	; disable further timer 0 interrupts
	bsf	progflags, capdone ; set flag signifying packet capture done

	movlw	-8		; start capturing another 8 bits
	movwf	capbit
	incf	capptr, f	; make sure to include last capture byte
	movlw	capbufferend	; have we overflowed the 
	subwf	capptr, w	; capture buffer?
	btfss	STATUS, Z
	goto	ClearCapByte2

	movlw	capbuffer	; yes, roll over to beginning
	movwf	capptr

ClearCapByte2
	movf	capptr, w
	movwf	FSR	
	clrf	INDF		; clear capture byte (incomplete captures)

EndInterrupt
	movf	intfsrsave, w	; restore indirect pointer
	movwf	FSR
	swapf	intstatussave, w; restore STATUS register
	movwf	STATUS
	swapf	intwsave, f	; restore w register
	swapf	intwsave, w
	retfie
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

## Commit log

2014-07-03 fix serial communication for ARCHOS (C4,5,6 didnt work)
    [vwcdpic-2.8pre3.asm]
2015-02-05 fix swith cd->radio->cd on audi concert1(chorus1)
    [vwcdpic-2.8pre3.asm]
2015-03-06 README update
    [dump_vwcdpic_v2.txt, dump_vwcdpic_v3.txt]
2015-08-24 comment pin fix
2015-10-02 move from soft repo
    [dump_vwcdpic_v2.txt, dump_vwcdpic_v3.txt]
2015-10-09 hw part
    [vwcdpic.kicad_pcb, vwcdpic.sch, vwcdpic_THT.kicad_pcb]
2015-10-09 update, new schematics file
    [vwcdpic.kicad_pcb, vwcdpic.sch, vwcdpic_THT.kicad_pcb]
2015-10-09 moved vwcdpic hw part
    [vwcdpic.kicad_pcb, vwcdpic.sch, vwcdpic_THT.kicad_pcb]
2015-10-13 remove unneedid dumps
    [dump_vwcdpic_v2.txt, dump_vwcdpic_v3.txt]
2015-12-10 pictures of assembled unit
2016-03-10 hw upgrade
    [vwcdpic.kicad_pcb, vwcdpic.sch]
2016-03-21 assembly plans
    [vwcdpic.kicad_pcb, vwcdpic.sch]
2016-03-23 try to fix concert 1 turn on, sometimes it's jast hangs
    [vwcdpic-2.8pre3.asm]
2017-04-19 THT kit assambly plan plus BOM
    [vwcdpic_THT.csv]
2018-06-28 fix #1, fix ignoring TP-INFO
    [vwcdpic-2.8pre3.asm]
2018-10-26 hw and pictures changes
    [vwcdpic.kicad_pcb, vwcdpic_THT.kicad_pcb]
2020-07-16 move to new kicad version
    [vwcdpic.kicad_sch, vwcdpic.sch]
2020-07-16 new kicad version
    [vwcdpic.kicad_pcb]
2020-07-16 interactive bom link
2021-11-07 Update README.md
    https://forum.kicad.info/t/warning-avoid-all-links-to-kicad-pcb-org-use-kicad-org/31521
2022-04-22 programing notes
    [vwcdpic.kicad_pcb]
2022-09-17 bk3266 board with pic
    [vwcdpic_with_BT-B_Mask.gbs, vwcdpic_with_BT-B_Silkscreen.gbo, vwcdpic_with_BT-Back.gbl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]
2022-09-21 add (C)
    [vwcdpic_with_BT.kicad_pcb, vwcdpic_with_BT.kicad_sch]

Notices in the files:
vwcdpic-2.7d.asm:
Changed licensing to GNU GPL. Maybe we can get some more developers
